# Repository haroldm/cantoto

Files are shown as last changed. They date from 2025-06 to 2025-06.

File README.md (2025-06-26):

# cantoto

Hardware and firmware to convert infotaimment CAN messages.

This project is inspired from [canbox](https://github.com/smartgauges/canbox) and was originally a [fork](https://github.com/haroldm/canbox) of it.

Messages converted:
* Illumination (autoradio dark or light mode) is converted to a 0V/12V binary signal
* Accessory power is converted to a 0V/12V binary signal
* Steering wheel media keys are converted to a voltage between 0 and 5v that will be sensed by the radio

Compatible vehicles: Audi A3 8P facelift (and probably other cars on the PQ35 platform).
Compatible radios: ATOTO F7 (and probably most third-party radio)

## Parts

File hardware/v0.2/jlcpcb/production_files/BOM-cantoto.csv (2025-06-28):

Comment | Designator | Footprint | LCSC | Quantity
PHB2.0-02-16PWZ | U5 | CONN-TH_16P-P2.00_S16B-PADSS-1 | C19077320 | 1
4.7k | R16,R17 | R_0402_1005Metric | C25900 | 2
TJA1040T/CM,118 | U3 | SOIC-8_L5.0-W4.0-P1.27-LS6.0-BL | C6951 | 1
TS-1088-AR02016 | SW2 | SW-SMD_L3.9-W3.0-P4.45 | C720477 | 1
SMBJ15CA_C78809 | D1 | SMB_L4.6-W3.6-LS5.3-BI | C78809 | 1
10u | C18 | C_1206_3216Metric |  | 1
22u | C12 | C_0805_2012Metric |  | 1
2.2k | R6 | R_0402_1005Metric |  | 1
STM32F103C8T6 | U1 | LQFP-48_7x7mm_P0.5mm |  | 1
10p | C11 | C_0402_1005Metric |  | 1
AO3401A | Q2 | SOT-23 |  | 1
MMBT3904 | Q1 | SOT-23 |  | 1
100n | C9 | C_0402_1005Metric |  | 1
10k | R14 | R_0402_1005Metric |  | 1
MCP4018 | U6 | SOT-363_SC-70-6 |  | 1
10n | C6 | C_0402_1005Metric |  | 1
10k | R10 | R_0402_1005Metric |  | 1
22u | C13 | C_0805_2012Metric |  | 1
10k | R1 | R_0402_1005Metric |  | 1
10u | C16 | C_1206_3216Metric |  | 1
100n | C2 | C_0402_1005Metric |  | 1
10k | R4 | R_0402_1005Metric |  | 1
10u | C17 | C_1206_3216Metric |  | 1
Polyfuse | F1 | Fuse_1812_4532Metric |  | 1
SW_SPDT | SW1 | SW_SPDT_PCM12 |  | 1
100n | C3 | C_0402_1005Metric |  | 1
100n | C15 | C_0805_2012Metric |  | 1
10k | R7 | R_0402_1005Metric |  | 1
100n | C4 | C_0402_1005Metric |  | 1
4.7k | R5 | R_0402_1005Metric |  | 1
1u | C8 | C_0402_1005Metric |  | 1
10k | R2 | R_0402_1005Metric |  | 1
100n | C1 | C_0402_1005Metric |  | 1
2.2k | R8 | R_0402_1005Metric |  | 1
Conn_ARM_JTAG_SWD_10 | J1 | PinHeader_2x05_P1.27mm_Vertical_SMD |  | 1
10u | C5 | C_0603_1608Metric |  | 1
2.2k | R11 | R_0402_1005Metric |  | 1
10p | C10 | C_0402_1005Metric |  | 1
AMS1117-3.3 | U2 | SOT-223-3_TabPin2 |  | 1
10k | R12 | R_0402_1005Metric |  | 1
AO3401A | Q4 | SOT-23 |  | 1
16MHz | Y1 | Crystal_SMD_3225-4Pin_3.2x2.5mm |  | 1
MMBT3904 | Q3 | SOT-23 |  | 1
330n | C14 | C_0805_2012Metric |  | 1
100k | R9 | R_0402_1005Metric |  | 1
LM78M05_TO252 | U4 | TO-252-2 |  | 1
120R | FB1 | L_0603_1608Metric |  | 1
1u | C7 | C_0402_1005Metric |  | 1
100k | R15 | R_0402_1005Metric |  | 1
10k | R3 | R_0402_1005Metric |  | 1
2.2k | R13 | R_0402_1005Metric |  | 1

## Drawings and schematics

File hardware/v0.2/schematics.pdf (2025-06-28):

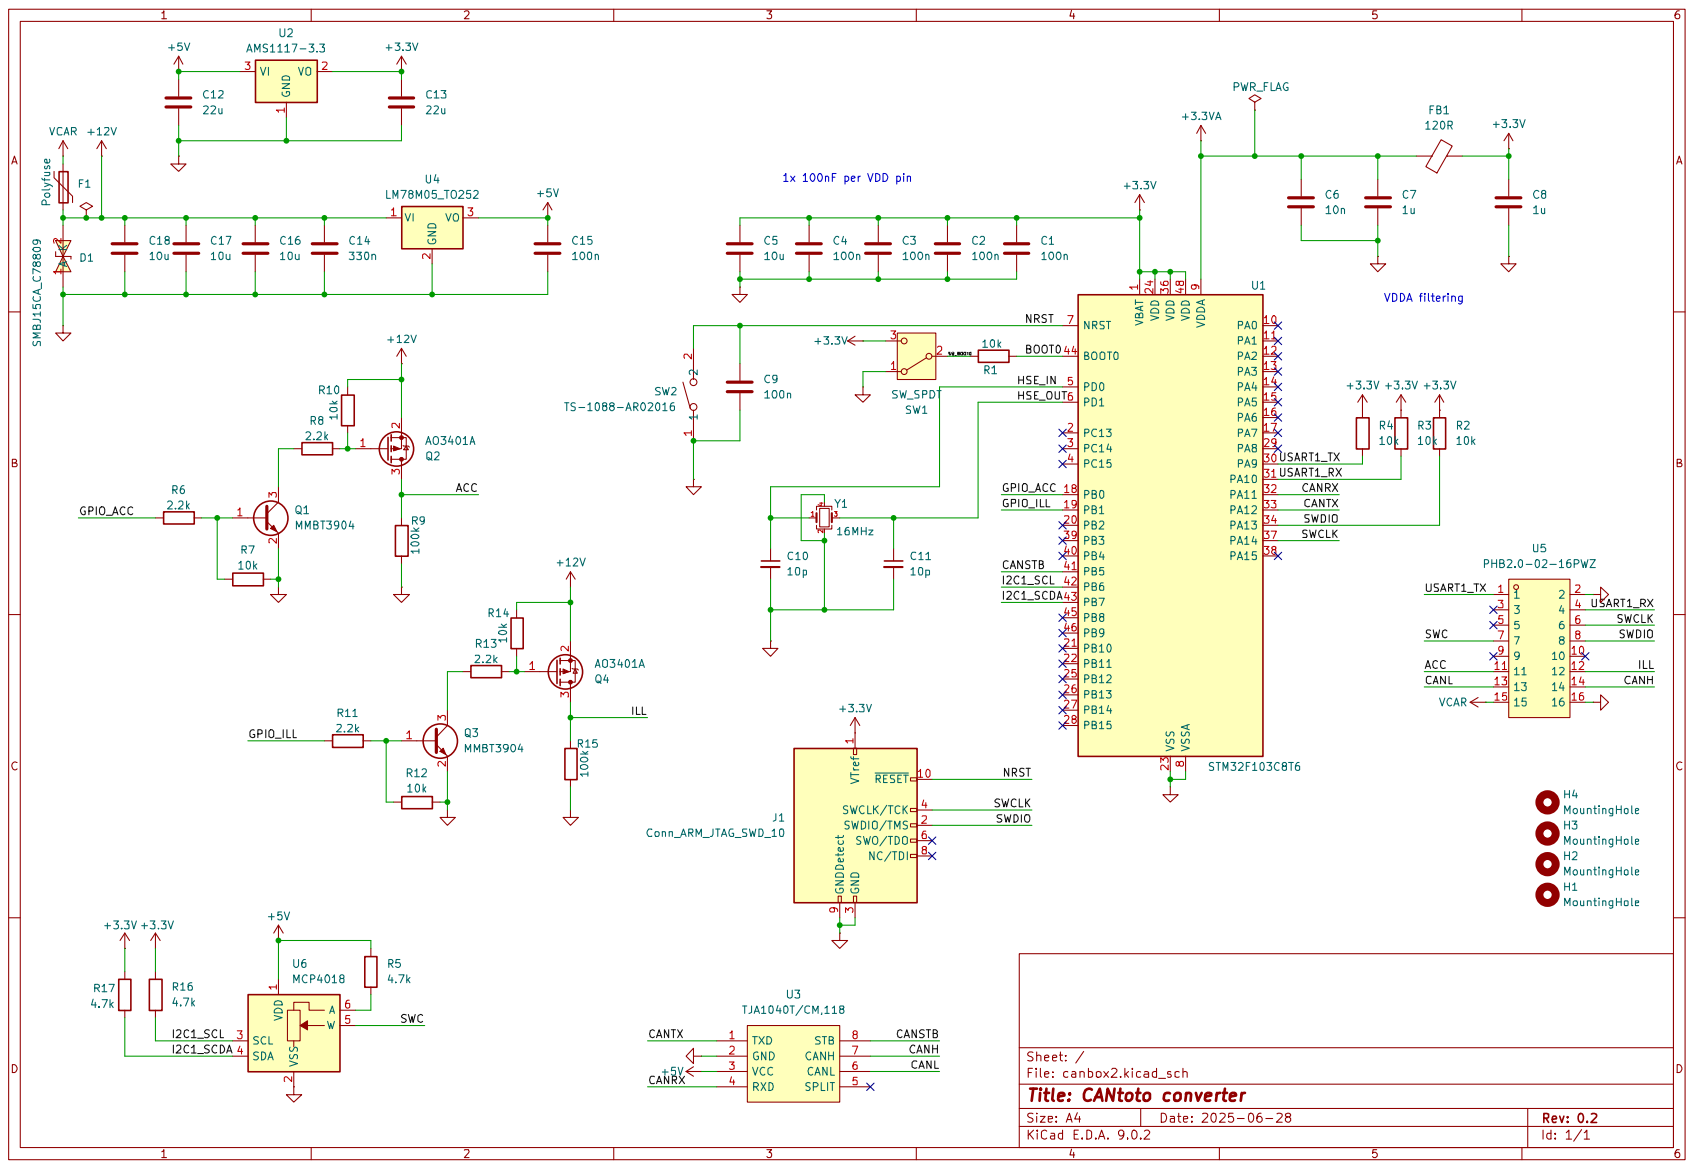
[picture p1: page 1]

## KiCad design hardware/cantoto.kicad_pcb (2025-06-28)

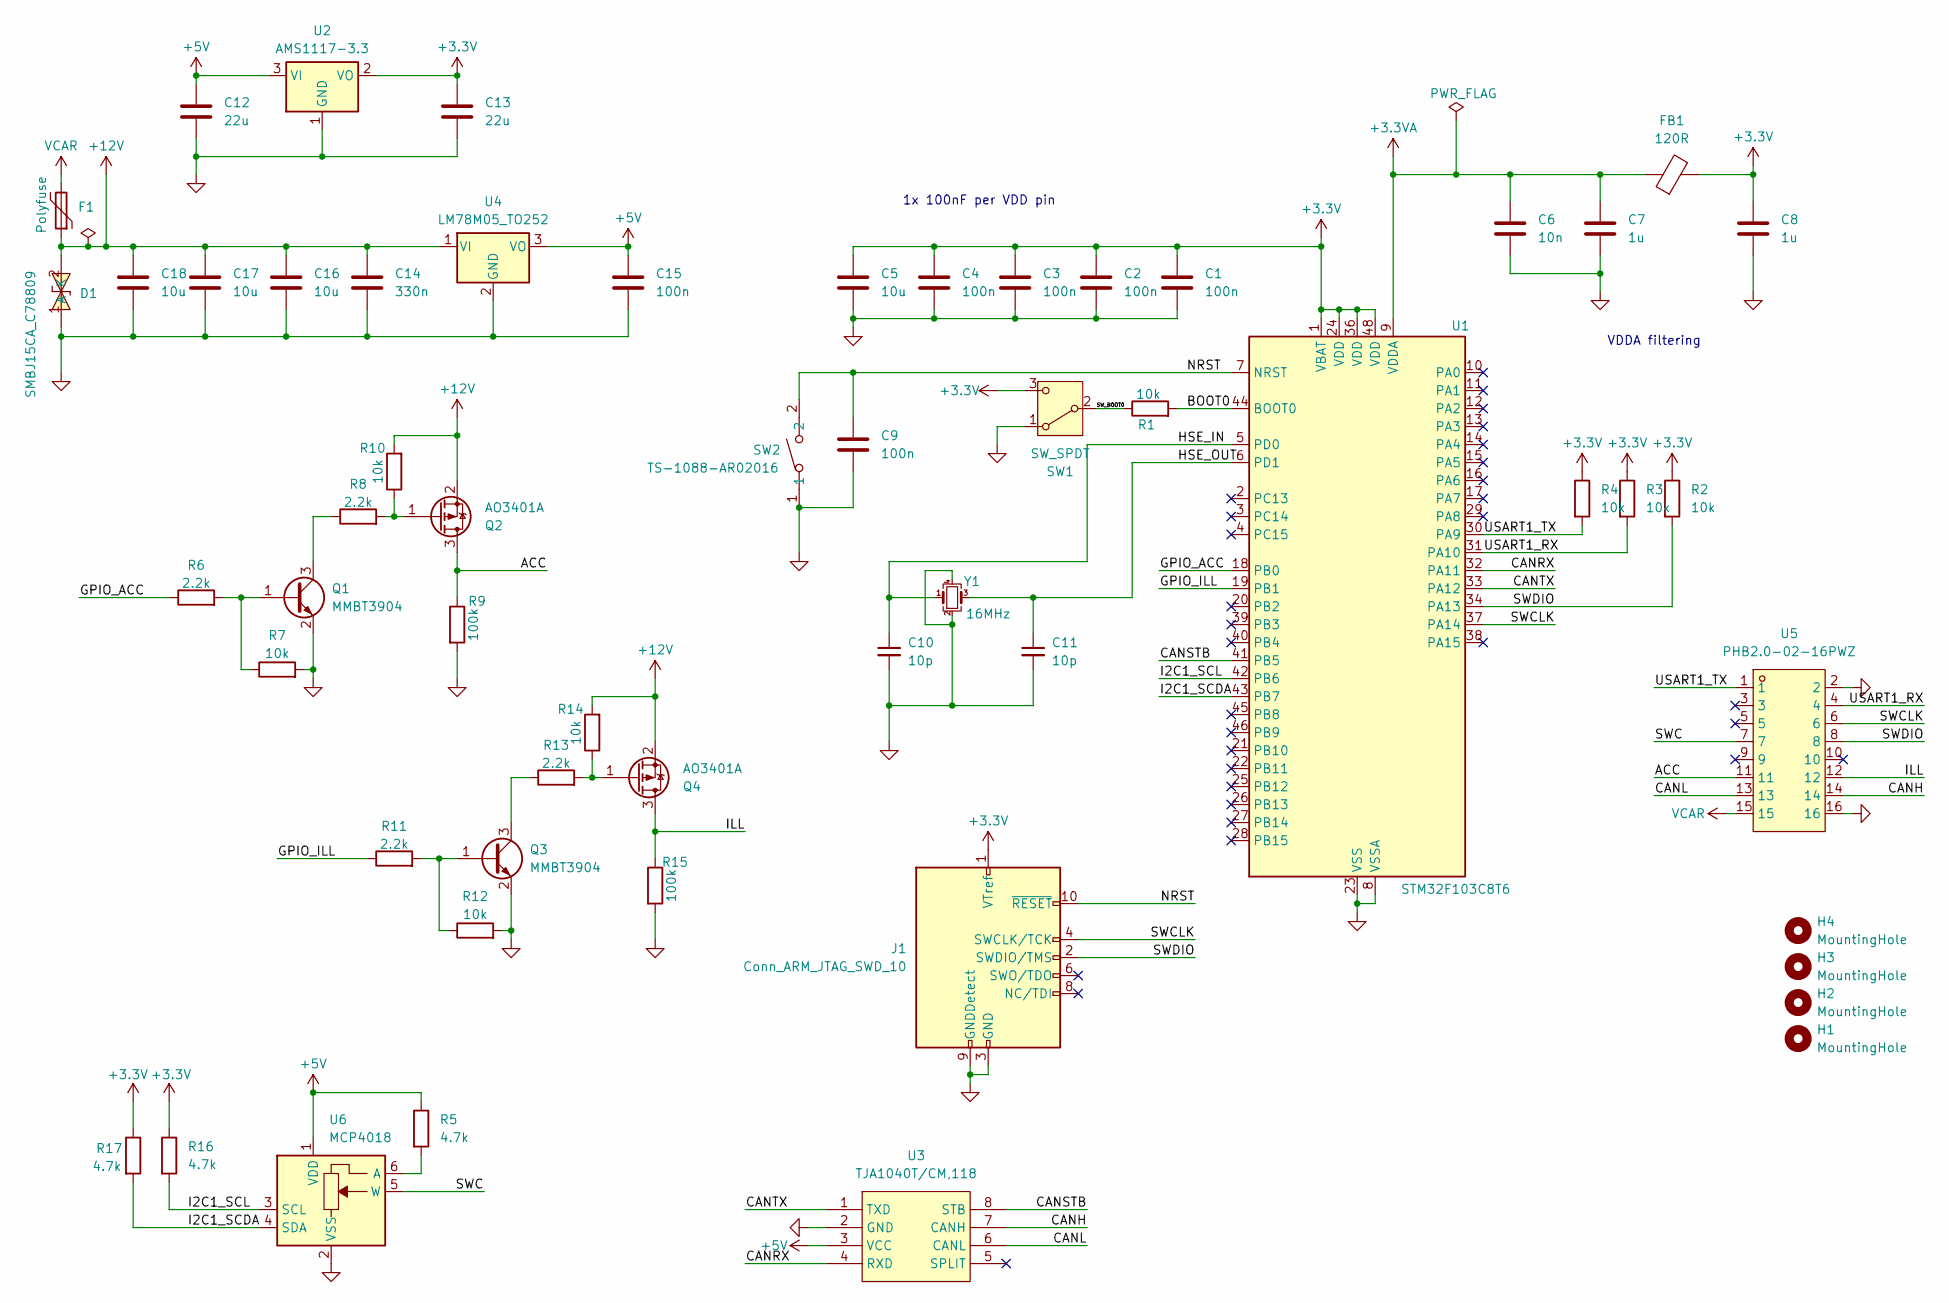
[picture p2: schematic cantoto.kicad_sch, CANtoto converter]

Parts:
C1, C2, C3, C4, C9: 100n; C_0402_1005Metric
C5: 10u; C_0603_1608Metric
C6: 10n; C_0402_1005Metric
C7, C8: 1u; C_0402_1005Metric
C10, C11: 10p; C_0402_1005Metric
C12, C13: 22u; C_0805_2012Metric
C14: 330n; C_0805_2012Metric
C15: 100n; C_0805_2012Metric
C16, C17, C18: 10u; C_1206_3216Metric
D1: SMBJ15CA_C78809; SMB_L4.6-W3.6-LS5.3-BI; LCSC Part C78809
F1: Polyfuse; Fuse_1812_4532Metric
FB1: 120R; L_0603_1608Metric
H1, H2, H3, H4: MountingHole; MountingHole_3mm
J1: Conn_ARM_JTAG_SWD_10; PinHeader_2x05_P1.27mm_Vertical_SMD
Q1, Q3: MMBT3904; SOT-23
Q2, Q4: AO3401A; SOT-23
R1, R2, R3, R4, R7, R10, R12, R14: 10k; R_0402_1005Metric
R5, R16, R17: 4.7k; R_0402_1005Metric
R6, R8, R11, R13: 2.2k; R_0402_1005Metric
R9, R15: 100k; R_0402_1005Metric
SW1: SW_SPDT; SW_SPDT_PCM12
SW2: TS-1088-AR02016; SW-SMD_L3.9-W3.0-P4.45; LCSC Part C720477
U1: STM32F103C8T6; LQFP-48_7x7mm_P0.5mm
U2: AMS1117-3.3; SOT-223-3_TabPin2
U3: TJA1040T/CM,118; SOIC-8_L5.0-W4.0-P1.27-LS6.0-BL; LCSC Part C6951
U4: LM78M05_TO252; TO-252-2
U5: PHB2.0-02-16PWZ; CONN-TH_16P-P2.00_S16B-PADSS-1; LCSC Part C19077320
U6: MCP4018; SOT-363_SC-70-6
Y1: 16MHz; Crystal_SMD_3225-4Pin_3.2x2.5mm

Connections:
+3.3V: C1.1, C2.1, C3.1, C4.1, C5.1, C8.1, C13.1, FB1.2, J1.1 (VTref), R2.1, R3.1, R4.1, R16.1, R17.1, SW1.3 (C), U1.1 (VBAT), U1.24 (VDD), U1.36 (VDD), U1.48 (VDD), U2.2 (VO)
+3.3VA: C6.1, C7.1, FB1.1, U1.9 (VDDA)
+5V: C12.1, C15.1, R5.1, U2.3 (VI), U3.3 (VCC), U4.3 (VO), U6.1 (VDD)
+12V: C14.1, C16.1, C17.1, C18.1, D1.2 (A), F1.1, Q2.2 (S), Q4.2 (S), R10.2, R14.2, U4.1 (VI)
/ACC: Q2.3 (D), R9.1, U5.11
/BOOT0: R1.2, U1.44 (BOOT0)
/CANH: U3.7 (CANH), U5.14
/CANL: U3.6 (CANL), U5.13
/CANRX: U1.32 (PA11), U3.4 (RXD)
/CANSTB: U1.41 (PB5), U3.8 (STB)
/CANTX: U1.33 (PA12), U3.1 (TXD)
/GPIO_ACC: R6.1, U1.18 (PB0)
/GPIO_ILL: R11.1, U1.19 (PB1)
/HSE_IN: C10.1, U1.5 (PD0), Y1.1
/HSE_OUT: C11.1, U1.6 (PD1), Y1.3
/I2C1_SCDA: R17.2, U1.43 (PB7), U6.4 (SDA)
/I2C1_SCL: R16.2, U1.42 (PB6), U6.3 (SCL)
/ILL: Q4.3 (D), R15.1, U5.12
/NRST: C9.1, J1.10 (~RESET), SW2.2, U1.7 (NRST)
/SWC: U5.7, U6.5 (W)
/SWCLK: J1.4 (SWCLK/TCK), U1.37 (PA14), U5.6
/SWDIO: J1.2 (SWDIO/TMS), R2.2, U1.34 (PA13), U5.8
/SW_BOOT0: R1.1, SW1.2 (B)
/USART1_RX: R3.2, U1.31 (PA10), U5.4
/USART1_TX: R4.2, U1.30 (PA9), U5.1
GND: C1.2, C2.2, C3.2, C4.2, C5.2, C6.2, C7.2, C8.2, C9.2, C10.2, C11.2, C12.2, C13.2, C14.2, C15.2, C16.2, C17.2, C18.2, D1.1 (K), J1.3 (GND), J1.5 (GND), J1.9 (GNDDetect), Q1.2 (E), Q3.2 (E), R7.2, R9.2, R12.2, R15.2, SW1.1 (A), SW2.1, U1.8 (VSSA), U1.23 (VSS), U1.35 (VSS), U1.47 (VSS), U2.1 (GND), U3.2 (GND), U4.2 (GND), U5.2, U5.16, U6.2 (VSS), Y1.2, Y1.4
unnamed: Q1.1 (B), R6.2, R7.1
unnamed: Q1.3 (C), R8.1
unnamed: Q2.1 (G), R8.2, R10.1
unnamed: Q3.1 (B), R11.2, R12.1
unnamed: Q3.3 (C), R13.1
unnamed: Q4.1 (G), R13.2, R14.1
unnamed: R5.2, U6.6 (A)
VCAR: F1.2, U5.15

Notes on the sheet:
VDDA filtering
1x 100nF per VDD pin

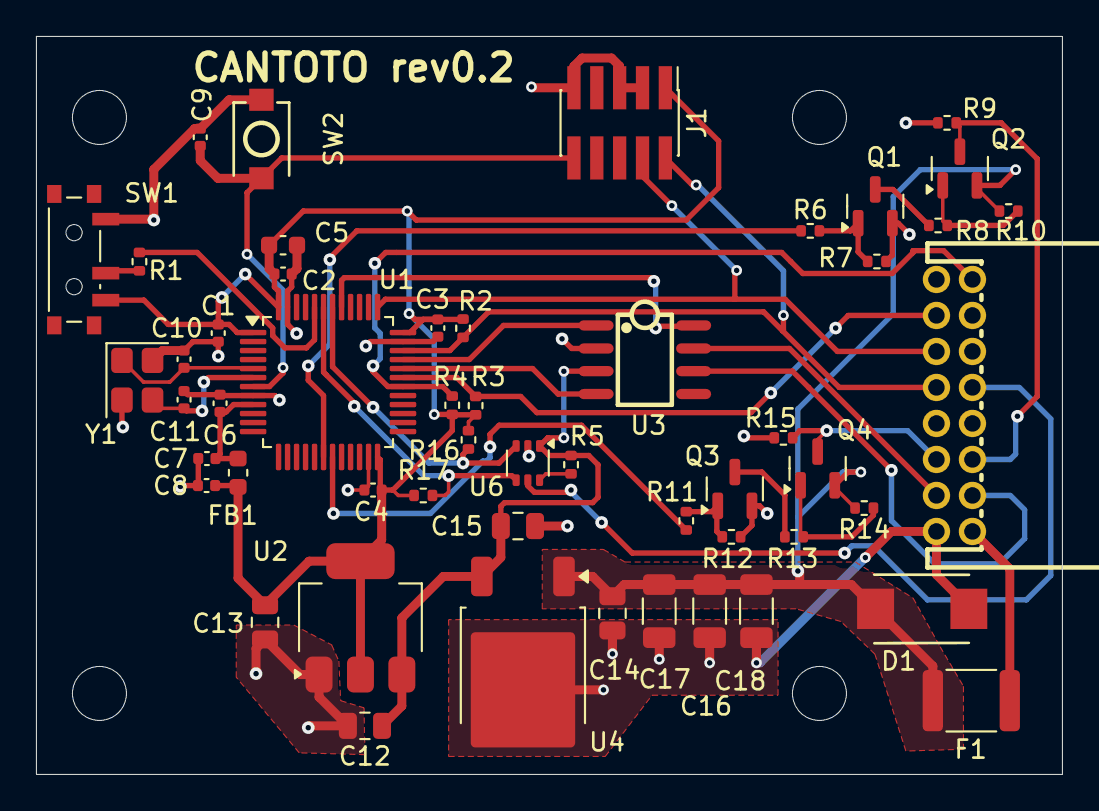
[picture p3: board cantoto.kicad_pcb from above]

Board: 2 copper layers, 57.0 x 41.0 mm, 56 parts (0 on the bottom side), 34 nets.

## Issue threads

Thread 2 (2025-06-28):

Hardware improvements

haroldm, 2025-06-28:
- [ ] Add NRST to the PHB connector to allow programming the board without opening its case
- [ ] Explore the usefulness of providing JTAG instead of SWD
- [ ] Connect BOOT0 to GND by default. Add a cutable trace so it's controllable by a switch if needed.

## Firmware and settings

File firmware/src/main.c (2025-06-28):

#include <libopencm3/stm32/i2c.h>
#include <libopencm3/stm32/rcc.h>

#include <inttypes.h>
#include <stdio.h>
#include <string.h>

#include "system/can.h"
#include "system/gpio.h"
#include "system/i2c.h"
#include "system/tick.h"
#include "system/usart.h"

#include "can_parser.h"
#include "clock.h"
#include "state.h"

#define CMD_BUFFER_SIZE 64

static void in_process(struct can_t *can, uint8_t ticks,
                       struct msg_desc_t *msg_desc, uint8_t desc_num) {
  uint8_t msgs_num = hw_can_get_msg_nums(can);
  uint32_t all_packs = 0;

  for (uint8_t i = 0; i < msgs_num; i++) {

    struct msg_can_t msg;
    if (!hw_can_get_msg(can, &msg, i))
      continue;

    all_packs += msg.num;

    for (uint32_t j = 0; j < desc_num; j++) {

      struct msg_desc_t *desc = &msg_desc[j];

      // special purpose - any activity on the bus
      if (0 == desc->id) {

        if (desc->in_handler) {

          // last msg
          if (i == (msgs_num - 1)) {

            if (all_packs == desc->num)
              desc->tick += ticks;
            else
              desc->tick = 0;

            desc->num = all_packs;

            desc->in_handler(msg.data, desc);
          }
        }
      } else if (msg.id == desc->id) {

        if (desc->in_handler) {

          // no new packs, increase timeout
          if (msg.num == desc->num)
            desc->tick += ticks;
          else
            desc->tick = 0;

          desc->num = msg.num;

          desc->in_handler(msg.data, desc);
        }

        break;
      }
    }
  }
}

static void usart_process(void) {
  static uint8_t debugtmp = 25;
  static char cmd_buffer[CMD_BUFFER_SIZE];
  static uint8_t idx = 0;
  static bool last_was_cr = false;
  uint8_t ch = 0;

  if (!usart_read_ch(&ch))
    return;

  if (ch == '\n' && last_was_cr) {
    last_was_cr = false;
    return;
  }

  if (ch != '\n')
    usart_send_char(&ch);

  if (ch == '\r' || ch == '\n') {
    last_was_cr = (ch == '\r');

    if (idx == 0) {
      usart_send_string("\r\n> ");
      return;
    }

    cmd_buffer[idx] = '\0';

    if (strcmp(cmd_buffer, "d") == 0) {
      car_enable_debug();
      usart_send_string("\r\ndebug mode enabled");
    } else if (strcmp(cmd_buffer, "T") == 0) {
      toggle_manual_on();
      usart_send_string("\r\nToggled manual on");
    } else if (strcmp(cmd_buffer, "+") == 0) {
      set_simulating_media_key_press(true);
      process_key_press(0x06);
      usart_send_string("\r\nPressing vol+ for two seconds");
    } else if (strcmp(cmd_buffer, "-") == 0) {
      set_simulating_media_key_press(true);
      process_key_press(0x07);
      usart_send_string("\r\nPressing vol+ for two seconds");
    } else if (strcmp(cmd_buffer, "vol") == 0) {
      set_simulating_media_key_press(true);
      process_key_press(0xA7);
      usart_send_string("\r\nPressing vol button for two seconds");
    } else if (strcmp(cmd_buffer, "left") == 0) {
      set_simulating_media_key_press(true);
      process_key_press(0x08);
      usart_send_string("\r\nPressing left button for two seconds");
    } else if (strcmp(cmd_buffer, "l") == 0) {
      char tmp[80];
      snprintf(tmp, 80, "sending value %d for ~250ms", debugtmp);
      usart_send_string(tmp);
      set_simulating_media_key_press(true);
      hw_i2c_write(I2C1, 0x2F, debugtmp);
      debugtmp += 1;
      if (debugtmp >= 0x7f)
        debugtmp = 0;
    } else {
      usart_send_string("\r\nunknown command");
    }

    idx = 0;
    usart_send_string("\r\n> ");
    return;
  }

  if (idx < CMD_BUFFER_SIZE - 1) {
    cmd_buffer[idx++] = ch;
  } else {
    usart_send_string("\r\ncommand too long\r\n> ");
    idx = 0;
  }
}

static void reset_simulated_key_presses(void) {
  static uint8_t count = 0;
  if (get_simulating_media_key_press()) {
    if (count < 2) {
      count++;
    } else {
      count = 0;
      process_key_press(0);
      set_simulating_media_key_press(false);
    }
  }
}

int main(void) {
  clock_setup();
  gpio_setup();
  usart_setup();
  hw_systick_setup();

  struct can_t *can = hw_can_get_mscan();
  hw_can_setup(can, e_speed_100);
  can_parser_init();

  hw_i2c_setup();

  usart_send_string("\r\nCANTOTO firmware\r\n\r\n> ");

  while (1) {
    gpio_process();
    usart_process();
    if (timer.flag_5ms) {
      timer.flag_5ms = 0;
      in_process(can, 5, can_msgs, can_msgs_len);
    }
    if (timer.flag_250ms) {
      timer.flag_250ms = 0;
      reset_simulated_key_presses();
    }
  }

  return 0;
}

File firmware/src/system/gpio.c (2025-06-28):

#include <libopencm3/stm32/gpio.h>

#include "gpio.h"
#include "state.h"

#define ACC_PORT GPIOB
#define ACC_PIN GPIO0
#define ILL_PORT GPIOB
#define ILL_PIN GPIO1

void gpio_setup(void) {
  gpio_set_mode(ACC_PORT, GPIO_MODE_OUTPUT_2_MHZ, GPIO_CNF_OUTPUT_PUSHPULL,
                ACC_PIN);
  gpio_set_mode(ILL_PORT, GPIO_MODE_OUTPUT_2_MHZ, GPIO_CNF_OUTPUT_PUSHPULL,
                ILL_PIN);
}

void gpio_process(void) {
  if (car_get_acc() || get_manual_on()) {
    gpio_set(ACC_PORT, ACC_PIN);
  } else {
    gpio_clear(ACC_PORT, ACC_PIN);
  }
  if (car_get_darkmode()) {
    gpio_set(ILL_PORT, ILL_PIN);
  } else {
    gpio_clear(ILL_PORT, ILL_PIN);
  }
}

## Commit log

2025-06-26 Initial commit: set up dev env with PlatformIO
    [tigard_swd.cfg]
2025-06-26 Add CAN parser and timer setup
2025-06-26 Check that pre-commit passes without error on all files
    [can_parser.c]
2025-06-28 Add kicad project and v0.2 build files
    [BOM-canbox2.csv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]
2025-06-28 Rename kicad project
    [cantoto-CuBottom.gbr, cantoto-CuTop.gbr, cantoto-EdgeCuts.gbr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]
2025-06-28 Add rev0.2 marking to silkscreen
    [BOM-canbox2.csv, BOM-cantoto.csv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]
